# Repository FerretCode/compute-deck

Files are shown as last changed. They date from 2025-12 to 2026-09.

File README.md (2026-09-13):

# Compute Deck

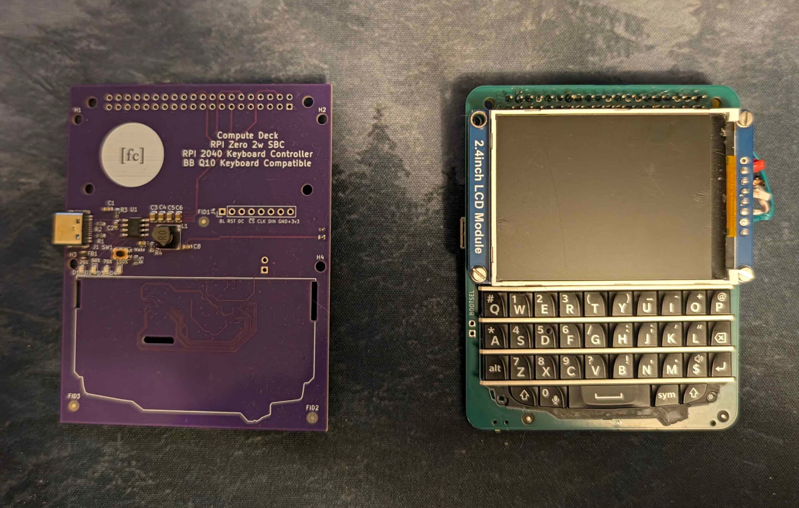
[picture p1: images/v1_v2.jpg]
Compute Deck v1 & v2


**Compute Deck** is an open-source portable Linux computer and cyberdeck platform. It features a BlackBerry Q10 physical keyboard, dedicated power management with LiPo charging, an RP2040 coprocessor serving as an I2C keyboard bridge, and a Linux compute module.

> [!WARNING]
> ### ⚠️ Hardware Revision Notice: RK3566 Migration In Progress
>
> Revisions 1 and 2 of this project were built and verified around a **Raspberry Pi Zero / Zero 2 W** form-factor header.
>
> The project is currently undergoing a major hardware architecture update to migrate from the Pi Zero header to an integrated Rockchip RK3566 SoC directly on the board.
---

## Project Overview & Key Features

- **Physical Keyboard Integration:** Uses a BlackBerry Q10 keyboard connected using a 24-pin Hirose BM14B connector.
- **Dedicated RP2040 Coprocessor:** Offloads the keyboard control from the processor, supporting debouncing, key remapping, and layer management.
- **I2C Slave Keyboard Bridge:** Communicates with the host system via I2C at address `0x1F`, sending keycodes to the main processor.
- **Power Management Subsystem:** Integrated IP5306 power bank SoC managing single-cell LiPo battery charging, 5V boost conversion, power routing, status LEDs, and soft-latching power control alongside an AMS1117-3.3 regulator.
- **Linux Host Virtual Keyboard Driver:** Python user-space daemon using Linux `/dev/uinput` and `evdev` to translate the RP2040 I2C keycodes into full USB keyboard input with support for modifiers.

---

## Repository Structure

```
compute-deck/
├── firmware/                   # RP2040 Coprocessor Firmware (Pico SDK C/C++)
│   ├── CMakeLists.txt          # CMake build configuration
│   ├── main.c                  # Keyboard matrix scanner, layer logic & I2C slave handler
├── hardware/                   # KiCad PCB & Schematic Design Files
│   ├── footprints/             # Custom KiCad component footprints
│   ├── symbols/                # Custom KiCad schematic symbols
├── host/                       # Host Linux Software & Services
│   ├── keyboard_driver.py      # Python I2C polling daemon & uinput event injector
│   ├── q10-keyboard.service    # Systemd service unit for boot startup
```

---

## RP2040 Firmware Setup

### Build Prerequisites

- [Raspberry Pi Pico SDK](https://github.com/raspberrypi/pico-sdk) configured in your environment (`PICO_SDK_PATH`).
- `cmake`
- GCC ARM Cross-compiler (`arm-none-eabi-gcc`)

### Building the Firmware

```bash
cd firmware
mkdir build
cd build
cmake ..
make -j$(nproc)
```

### Flashing

1. Short the `BOOTSEL` jumper on the board using tweezers or other conductive object while plugging in USB to enter the RP2040 into bootloader mode.
2. Drag and drop `q10_keyboard.uf2` onto the mounted `RPI-RP2` USB storage drive.

---

## Host Driver Setup (Linux / Raspberry Pi OS)

The host driver in `host/` runs on the Linux compute host (e.g. Raspberry Pi OS or Linux kernel with `/dev/uinput` enabled).

### 1. Enable I2C Interface
Enable the hardware I2C interface on the host SBC:

```bash
sudo raspi-config nonint do_i2c 0
```

### 2. Install Dependencies
```bash
sudo apt-get install python3-pip python3-smbus
pip3 install -r host/requirements.txt
```

### 3. Grant Permissions

Add your user to the `i2c` and `input` groups:

```bash
sudo usermod -aG i2c,input $USER
```

### 4. Running the Driver

Run the driver manually to verify key injection:

```bash
python3 host/keyboard_driver.py
```

### 5. Install as a Systemd Daemon

To launch the keyboard driver automatically at boot:

```bash
sudo mkdir -p /opt/q10-keyboard
sudo cp host/keyboard_driver.py /opt/q10-keyboard/
sudo cp host/q10-keyboard.service /etc/systemd/system/
sudo systemctl daemon-reload
sudo systemctl enable --now q10-keyboard.service
```

---

## Keyboard Layout & Modifier Behavior

The physical layout follows the BlackBerry Q10 matrix mapping:

- **Shift:** One-shot modifier. Pressing Shift capitalizes the next key typed, and then automatically clears.
- **Alt:** Accesses numbers and secondary symbols printed on keycaps (e.g., Q -> `#`, W -> `1`, E -> `2`).
- **Sym:** Accesses extended navigation and punctuation symbols (e.g., Q -> `Esc`, W -> `Up`, A -> `Left`, S -> `Down`, D -> `Right`, T -> `Tab`).
- **Mic Key:** Mapped as Super. Supports tap-or-chord timeout (`0.4s`).
- **Ctrl:** Left Control key with chord support.

---

## Fabrication & Manufacturing

Production files generated for JLCPCB are stored under `hardware/production/`

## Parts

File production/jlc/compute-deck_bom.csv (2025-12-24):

Designator | Footprint | Quantity | Value | LCSC Part #
A1 | RASPBERRYPI-ZERO_RPI-ZERO | 1 | RASPBERRYPI-ZERO
C1, C2 | 0603 | 2 | 10u | C19702
C10, C11, C13, C14, C16, C17, C18, C23 | 0402 | 8 | 100n | C71687
C12 | 0603 | 1 | 1u | C14445
C15 | 0402 | 1 | 100n
C20 | 0603 | 1 | 100n | C1590
C21, C22 | 0402 | 2 | 15p | C1548
C3, C4, C5, C6 | 0805 | 4 | 22u | C29277
C7, C8 | 0603 | 2 | 22u | C60077
C9 | 0402 | 1 | 1u | C14445
D1, D2, D3, D4 | 0603 | 4 | LED_Small | C6695603
FB1 | 0603 | 1 | 600R | C1017
J1 | USB_C_Receptacle_HRO_TYPE-C-31-M-12 | 1 | USB_C_Receptacle_USB2.0_16P | C165948
J2 | JST_PH_S2B-PH-K_1x02_P2.00mm_Horizontal | 1 | Conn_01x02 | C157932
L1 | L_Taiyo-Yuden_NR-60xx | 1 | 1uH | C2903082
Q1 | SOT-23 | 1 | BSS138 | C52895
R1, R2 | 0603 | 2 | 5.1k | C23186
R10, R5 | 0603 | 2 | 10k | C25804
R3 | 0603 | 1 | 2R | C22977
R4 | 0603 | 1 | 0.5R | C45312
R6, R7 | 0603 | 2 | 27.4 | C177713
R8, R9 | 0603 | 2 | 1k | C21190
SW1 | SW_Push_1P1T_NO_CK_KMR2 | 1 | SW_Push | C221675
U1 | SOP127P600X165-9N | 1 | IP5306
U2 | QFN-56-1EP_7x7mm_P0.4mm_EP3.2x3.2mm | 1 | RP2040 | C2040
U3 | SOIC-8_5.3x5.3mm_P1.27mm | 1 | W25Q128JVS
U4 | BM14B(0.8)-24DS-0.4V(53) | 1 | BBQ10KBD
Y1 | Crystal_SMD_3225-4Pin_3.2x2.5mm | 1 | 12MHz | C9002

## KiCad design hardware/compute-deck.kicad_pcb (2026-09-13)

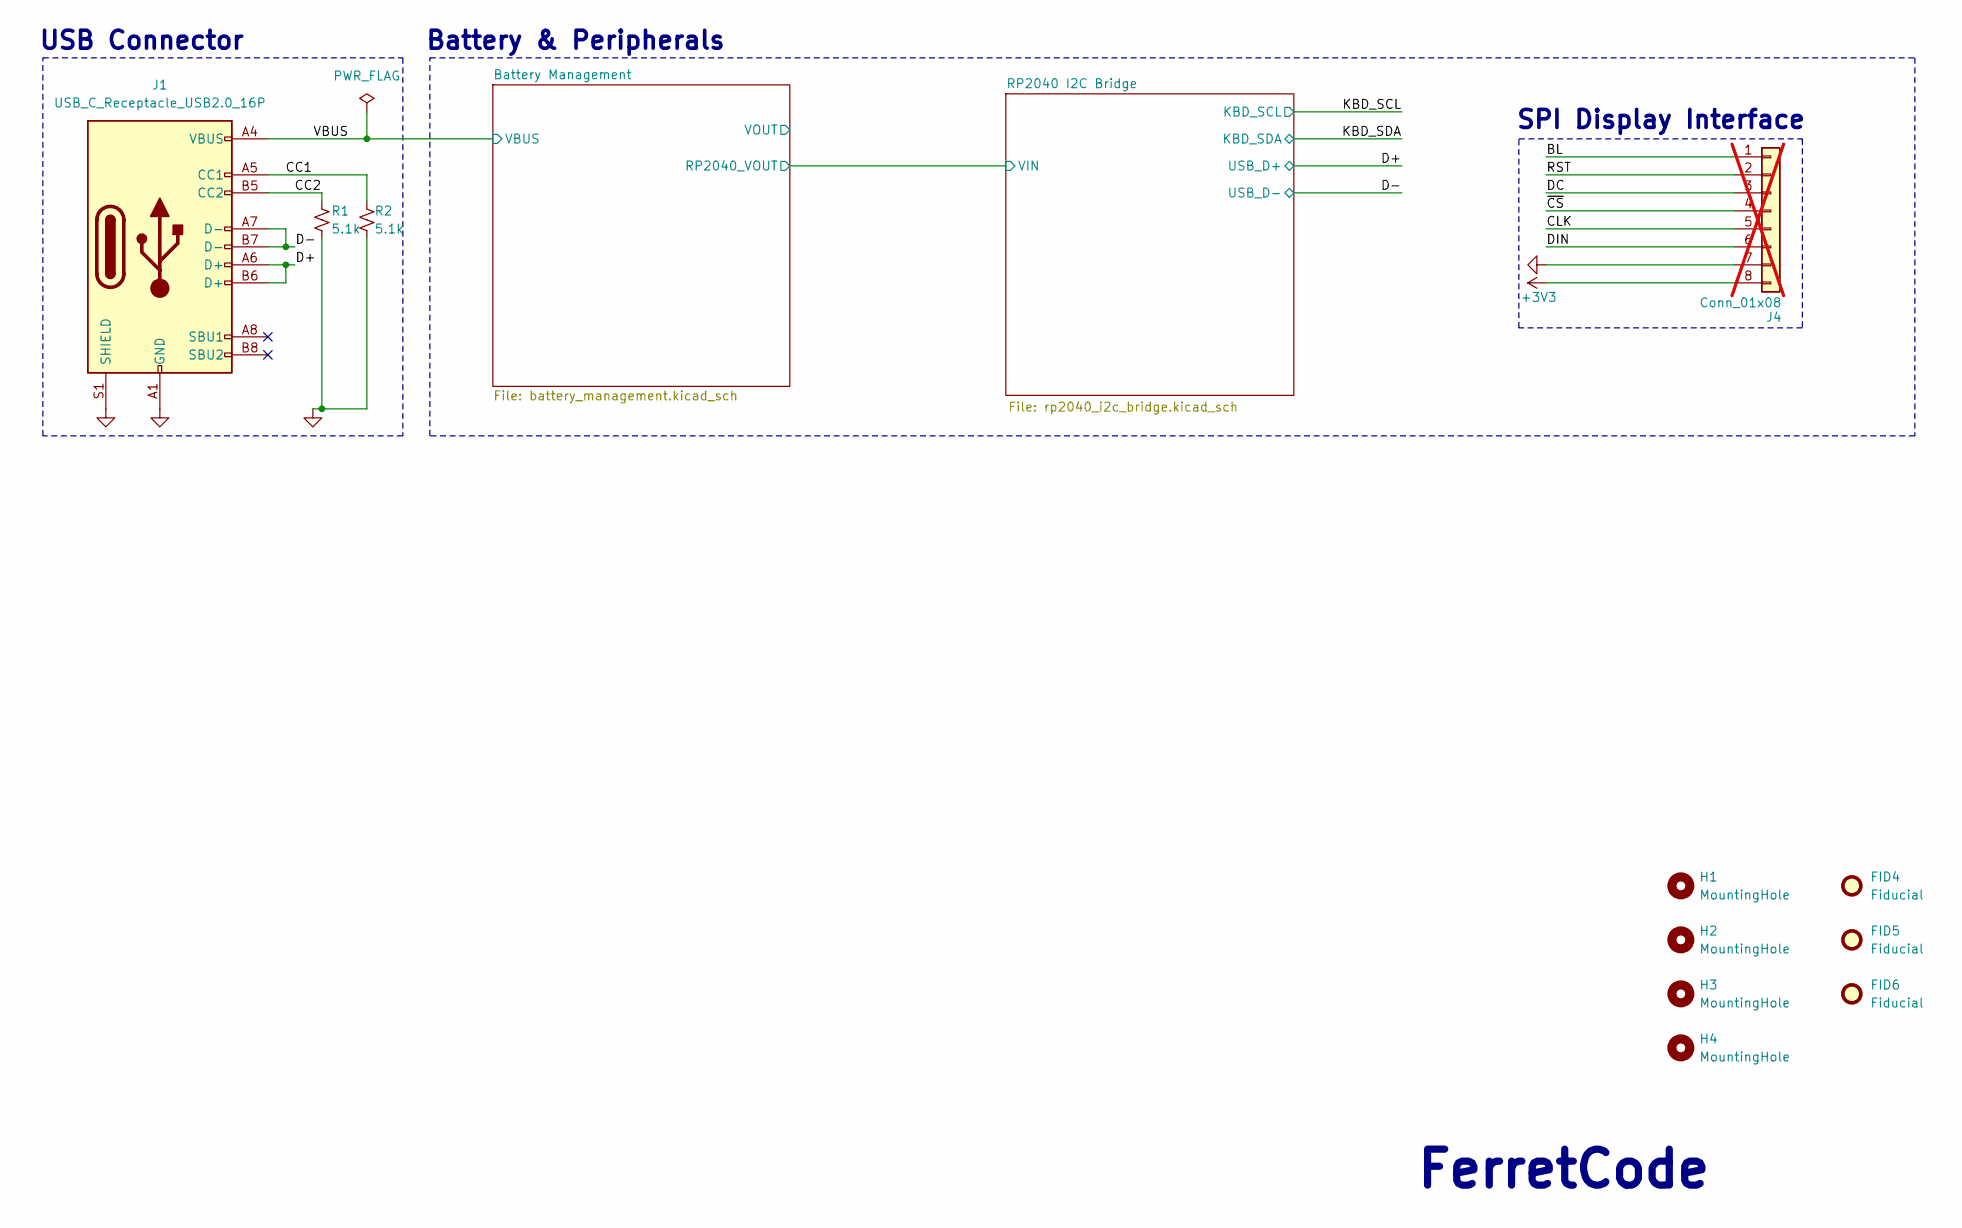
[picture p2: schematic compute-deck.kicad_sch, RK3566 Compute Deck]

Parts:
FID4, FID5, FID6: Fiducial; Fiducial_1mm_Mask3mm
H1, H2, H3, H4: MountingHole; MountingHole_2.7mm_M2.5
J1: USB_C_Receptacle_USB2.0_16P; USB_C_Receptacle_HRO_TYPE-C-31-M-12; LCSC PN C165948
J4: Conn_01x08; PinHeader_1x08_P2.54mm_Vertical; not fitted
R1, R2: 5.1k; R_0402_1005Metric; LCSC PN C23186

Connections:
+3V3: J4.8; also elsewhere on the board
/BL: J4.1; also elsewhere on the board
/CC1: J1.A5 (CC1), R2.1
/CC2: J1.B5 (CC2), R1.1
/CLK: J4.5; also elsewhere on the board
/D+: J1.A6 (D+), J1.B6 (D+); also elsewhere on the board
/D-: J1.A7 (D-), J1.B7 (D-); also elsewhere on the board
/DC: J4.3; also elsewhere on the board
/DIN: J4.6; also elsewhere on the board
/RST: J4.2; also elsewhere on the board
/VBUS: J1.A4 (VBUS), J1.A9 (VBUS), J1.B4 (VBUS), J1.B9 (VBUS); also elsewhere on the board
/~CS: J4.4; also elsewhere on the board
GND: J1.A1 (GND), J1.A12 (GND), J1.B1 (GND), J1.B12 (GND), J1.S1 (SHIELD), J4.7, R1.2, R2.2; also elsewhere on the board

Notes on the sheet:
Battery & Peripherals
FerretCode
SPI Display Interface
USB Connector

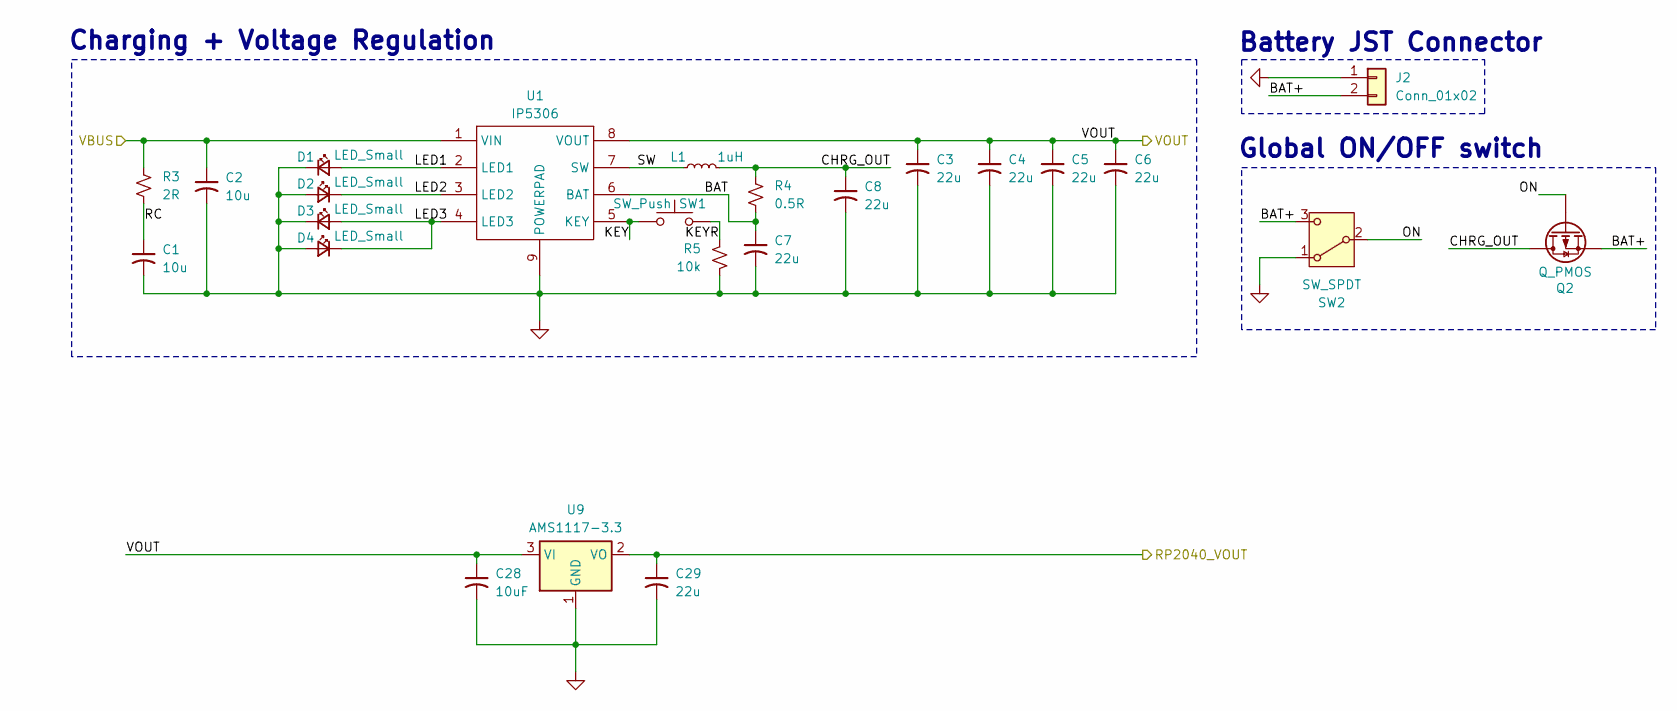
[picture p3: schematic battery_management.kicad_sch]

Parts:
C1, C2: 10u; C_0603_1608Metric; LCSC PN C19702
C3, C4, C5, C6: 22u; C_0805_2012Metric; LCSC PN C29277
C7: 22u; C_0402_1005Metric; LCSC PN C60077
C8: 22u; C_0603_1608Metric; LCSC PN C60077
C28: 10uF; C_0603_1608Metric; LCSC C19702
C29: 22u; C_0603_1608Metric; LCSC C59461
D1, D2, D3, D4: LED_Small; LED_0603_1608Metric; LCSC PN C6695603
J2: Conn_01x02; JST_PH_S2B-PH-K_1x02_P2.00mm_Horizontal; LCSC PN C157932
L1: 1uH; L_Taiyo-Yuden_NR-60xx; LCSC PN C2903082
Q2: Q_PMOS; SOT-23
R3: 2R; R_0603_1608Metric; LCSC PN C22977
R4: 0.5R; R_0402_1005Metric; LCSC PN C45312
R5: 10k; R_0402_1005Metric; LCSC PN C25804
SW1: SW_Push; SW_Push_1P1T_NO_CK_KMR2; LCSC PN C221675
SW2: SW_SPDT; SW_SPDT_PCM12
U1: IP5306; SOP127P600X165-9N
U9: AMS1117-3.3; SOT-223-3_TabPin2; LCSC C6186

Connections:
/BAT: C7.1, R4.2, U1.6 (BAT)
/BAT+: J2.2, Q2.S, SW2.3 (C)
/CHRG_OUT: C8.1, L1.2, Q2.D, R4.1
/KEY: SW1.1, U1.5 (KEY)
/KEYR: R5.1, SW1.2
/LED1: D1.2 (A), U1.2 (LED1)
/LED2: D2.1 (K), U1.3 (LED2)
/LED3: D3.2 (A), D4.1 (K), U1.4 (LED3)
/ON: Q2.G, SW2.2 (B)
/RC: C1.1, R3.2
/SW: L1.1, U1.7 (SW)
/VBUS: C2.1, R3.1, U1.1 (VIN); also elsewhere on the board
/VOUT: C3.1, C4.1, C5.1, C6.1, C28.1, U1.8 (VOUT), U9.3 (VI); also elsewhere on the board
GND: C1.2, C2.2, C3.2, C4.2, C5.2, C6.2, C7.2, C8.2, C28.2, C29.2, D1.1 (K), D2.2 (A), D3.1 (K), D4.2 (A), J2.1, R5.2, SW2.1 (A), U1.9 (POWERPAD), U9.1 (GND); also elsewhere on the board
unnamed: C29.1, U9.2 (VO)

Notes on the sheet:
Charging + Voltage Regulation
Global ON/OFF switch
Battery JST Connector

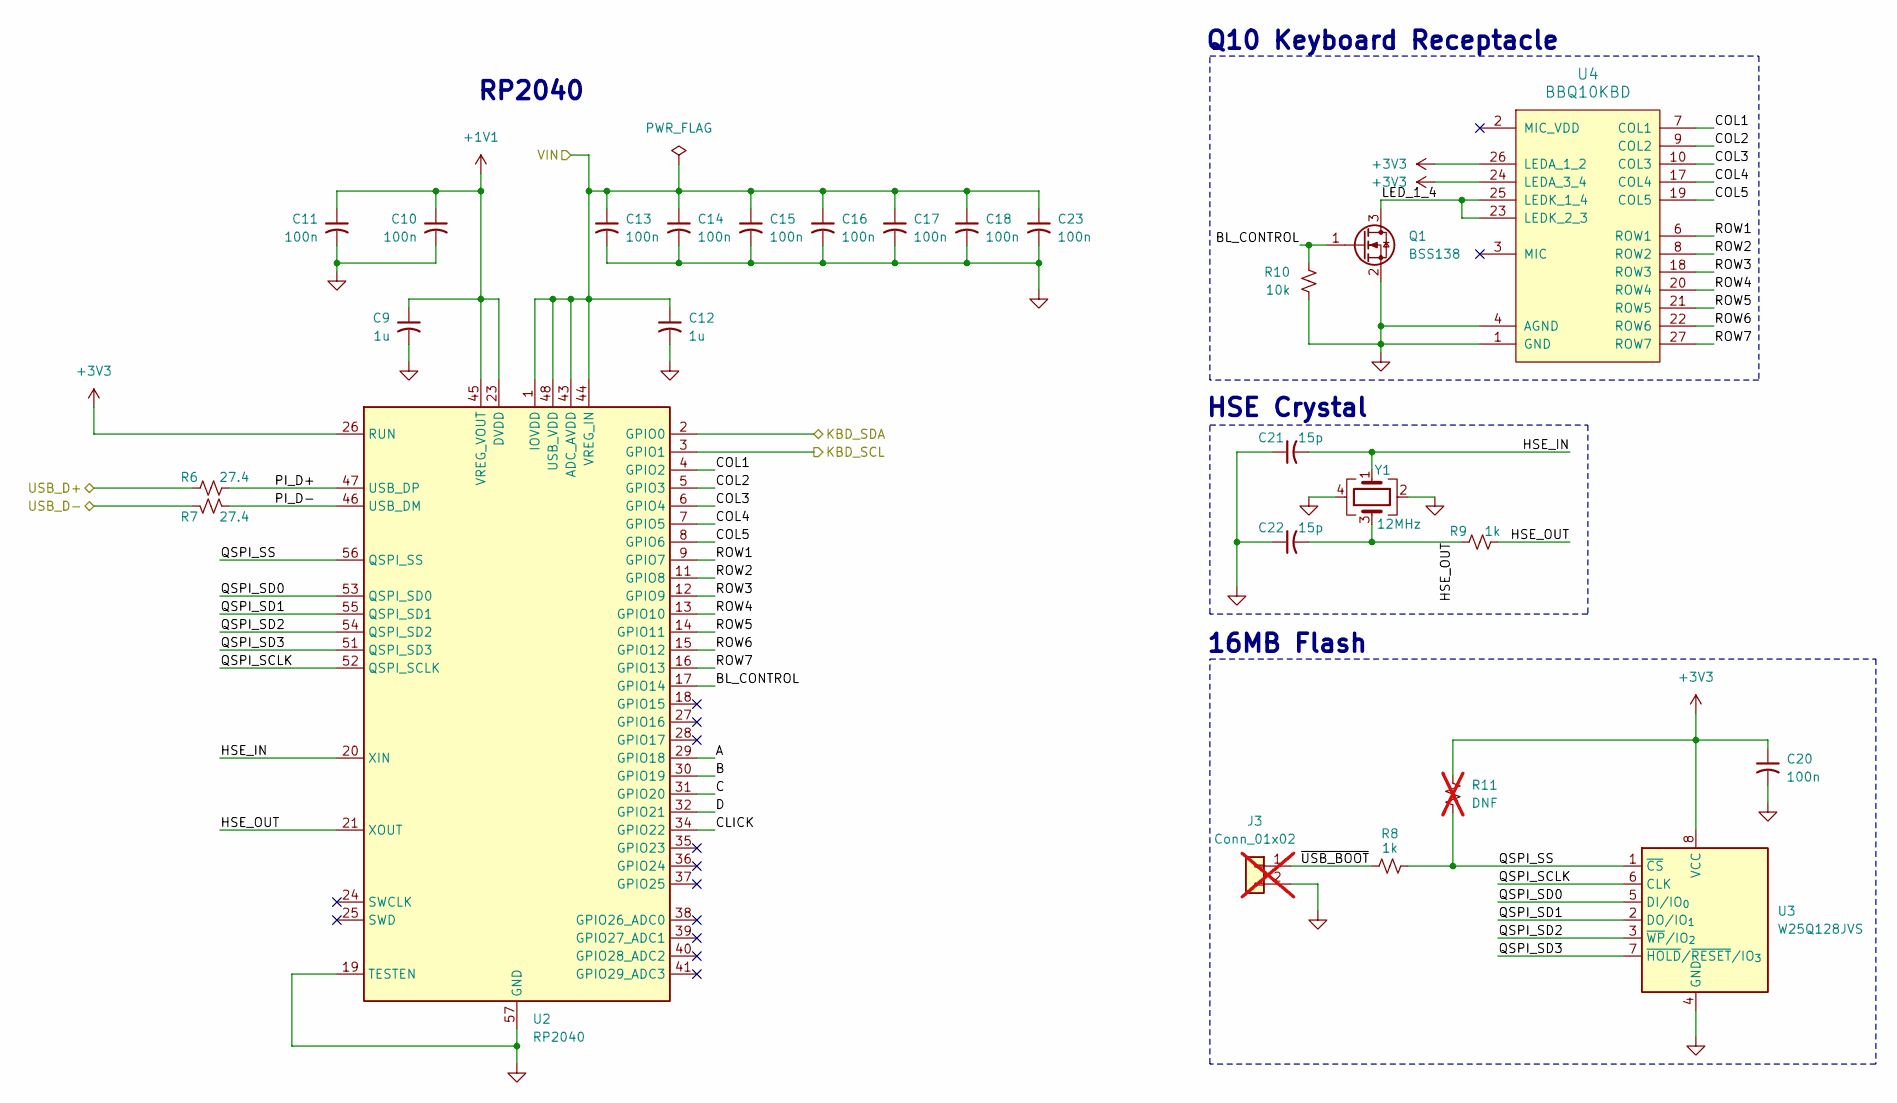
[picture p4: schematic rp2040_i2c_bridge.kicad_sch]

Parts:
C9: 1u; C_0402_1005Metric; LCSC PN C14445
C10, C11, C13, C14, C16, C17, C18: 100n; C_0402_1005Metric; LCSC PN C71687
C12: 1u; C_0603_1608Metric; LCSC PN C14445
C15: 100n; C_0402_1005Metric
C20: 100n; C_0603_1608Metric; LCSC PN C1590
C21, C22: 15p; C_0402_1005Metric; LCSC PN C1548
C23: 100n; C_0402_1005Metric_Pad0.74x0.62mm_HandSolder; LCSC PN C71687
J3: Conn_01x02; PinHeader_1x02_P2.54mm_Vertical; not fitted
Q1: BSS138; SOT-23; LCSC PN C52895
R6, R7: 27.4; R_0402_1005Metric; LCSC PN C177713
R8, R9: 1k; R_0402_1005Metric; LCSC PN C21190
R10: 10k; R_0603_1608Metric; LCSC PN C25804
R11: DNF; R_0402_1005Metric; not fitted
U2: RP2040; QFN-56-1EP_7x7mm_P0.4mm_EP3.2x3.2mm; LCSC PN C2040
U3: W25Q128JVS; SOIC-8_5.3x5.3mm_P1.27mm
U4: BBQ10KBD; BM14B(0.8)-24DS-0.4V(53)
Y1: 12MHz; Crystal_SMD_3225-4Pin_3.2x2.5mm; LCSC PN C9002

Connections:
+1V1: C9.1, C10.1, C11.1, U2.23 (DVDD), U2.45 (VREG_VOUT), U2.50 (DVDD)
+3V3: C12.1, C13.1, C14.1, C15.1, C16.1, C17.1, C18.1, C20.1, C23.1, R11.1, U2.1 (IOVDD), U2.10 (IOVDD), U2.22 (IOVDD), U2.26 (RUN), U2.33 (IOVDD), U2.42 (IOVDD), U2.43 (ADC_AVDD), U2.44 (VREG_IN), U2.48 (USB_VDD), U2.49 (IOVDD), U3.8 (VCC), U4.24 (LEDA_3_4), U4.26 (LEDA_1_2); also elsewhere on the board
/D+: R6.1; also elsewhere on the board
/D-: R7.1; also elsewhere on the board
/KBD_SCL: U2.3 (GPIO1); also elsewhere on the board
/KBD_SDA: U2.2 (GPIO0); also elsewhere on the board
/RP2040 I2C Bridge/A: U2.29 (GPIO18)
/RP2040 I2C Bridge/B: U2.30 (GPIO19)
/RP2040 I2C Bridge/BL_CONTROL: Q1.1 (G), R10.1, U2.17 (GPIO14)
/RP2040 I2C Bridge/C: U2.31 (GPIO20)
/RP2040 I2C Bridge/CLICK: U2.34 (GPIO22)
/RP2040 I2C Bridge/COL1: U2.4 (GPIO2), U4.7 (COL1)
/RP2040 I2C Bridge/COL2: U2.5 (GPIO3), U4.9 (COL2)
/RP2040 I2C Bridge/COL3: U2.6 (GPIO4), U4.10 (COL3)
/RP2040 I2C Bridge/COL4: U2.7 (GPIO5), U4.17 (COL4)
/RP2040 I2C Bridge/COL5: U2.8 (GPIO6), U4.19 (COL5)
/RP2040 I2C Bridge/D: U2.32 (GPIO21)
/RP2040 I2C Bridge/HSE_IN: C21.2, U2.20 (XIN), Y1.1
/RP2040 I2C Bridge/HSE_OUT: C22.2, R9.1, R9.2, U2.21 (XOUT), Y1.3
/RP2040 I2C Bridge/LED_1_4: Q1.3 (D), U4.23 (LEDK_2_3), U4.25 (LEDK_1_4)
/RP2040 I2C Bridge/PI_D+: R6.2, U2.47 (USB_DP)
/RP2040 I2C Bridge/PI_D-: R7.2, U2.46 (USB_DM)
/RP2040 I2C Bridge/QSPI_SCLK: U2.52 (QSPI_SCLK), U3.6 (CLK)
/RP2040 I2C Bridge/QSPI_SD0: U2.53 (QSPI_SD0), U3.5 (DI/IO_{0})
/RP2040 I2C Bridge/QSPI_SD1: U2.55 (QSPI_SD1), U3.2 (DO/IO_{1})
/RP2040 I2C Bridge/QSPI_SD2: U2.54 (QSPI_SD2), U3.3 (~WP/IO_{2})
/RP2040 I2C Bridge/QSPI_SD3: U2.51 (QSPI_SD3), U3.7 (~HOLD/~RESET/IO_{3})
/RP2040 I2C Bridge/QSPI_SS: R8.2, R11.2, U2.56 (QSPI_SS), U3.1 (~CS)
/RP2040 I2C Bridge/ROW1: U2.9 (GPIO7), U4.6 (ROW1)
/RP2040 I2C Bridge/ROW2: U2.11 (GPIO8), U4.8 (ROW2)
/RP2040 I2C Bridge/ROW3: U2.12 (GPIO9), U4.18 (ROW3)
/RP2040 I2C Bridge/ROW4: U2.13 (GPIO10), U4.20 (ROW4)
/RP2040 I2C Bridge/ROW5: U2.14 (GPIO11), U4.21 (ROW5)
/RP2040 I2C Bridge/ROW6: U2.15 (GPIO12), U4.22 (ROW6)
/RP2040 I2C Bridge/ROW7: U2.16 (GPIO13), U4.27 (ROW7)
/RP2040 I2C Bridge/~USB_BOOT: J3.1, R8.1
GND: C9.2, C10.2, C11.2, C12.2, C13.2, C14.2, C15.2, C16.2, C17.2, C18.2, C20.2, C21.1, C22.1, C23.2, J3.2, Q1.2 (S), R10.2, U2.19 (TESTEN), U2.57 (GND), U3.4 (GND), U4.1 (GND), U4.4 (AGND), U4.5 (GND), U4.11 (GND), U4.12 (GND), U4.13 (GND), U4.14 (GND), U4.15 (GND), U4.16 (GND), U4.28 (GND), Y1.2, Y1.4; also elsewhere on the board

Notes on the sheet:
Q10 Keyboard Receptacle
RP2040
16MB Flash
HSE Crystal

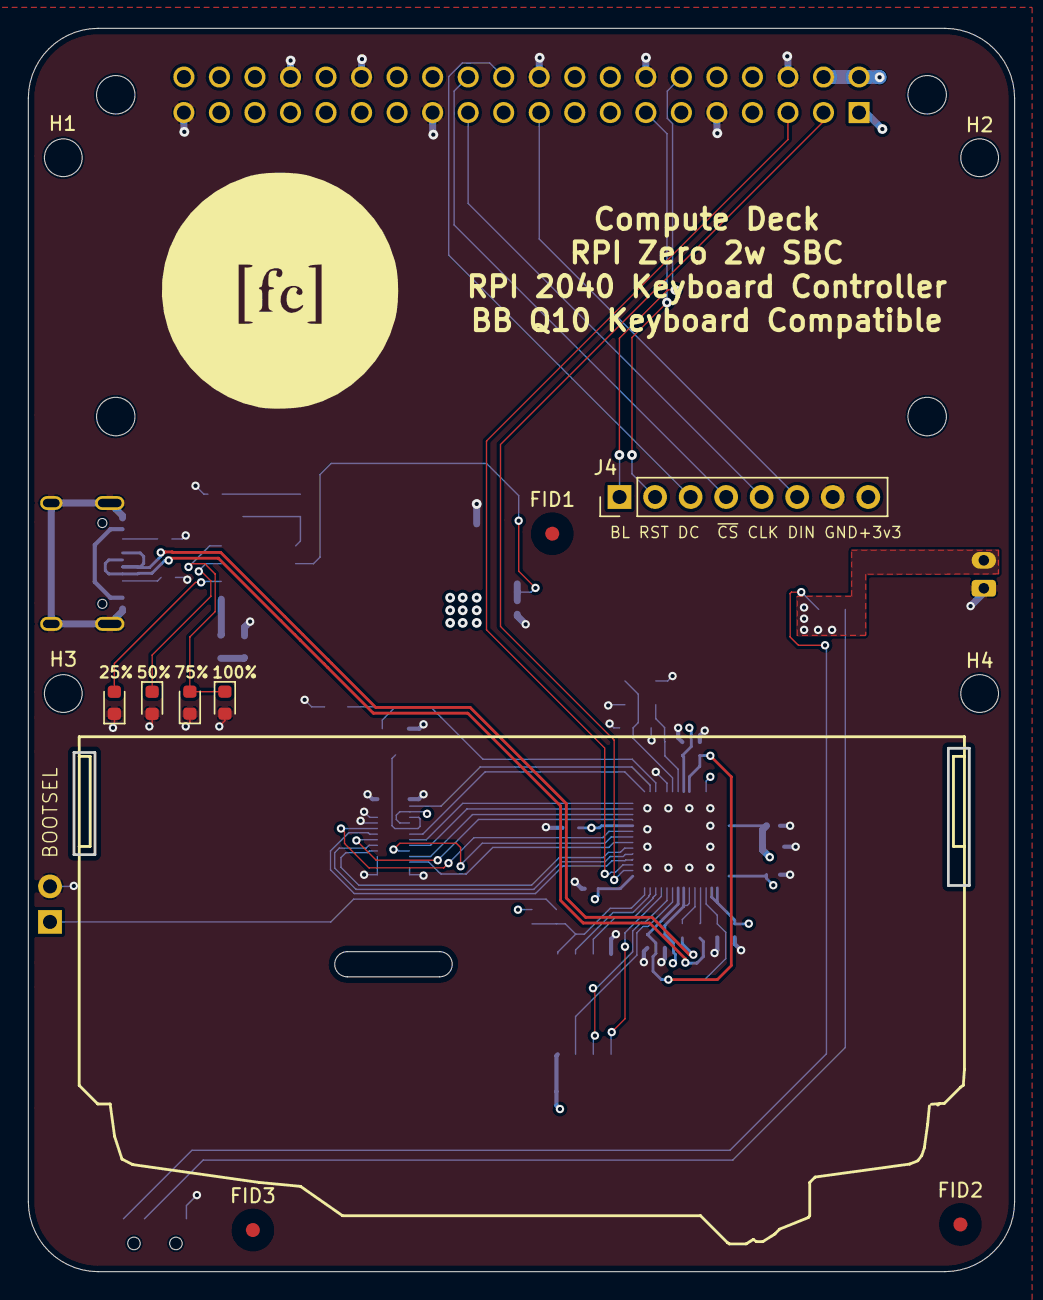
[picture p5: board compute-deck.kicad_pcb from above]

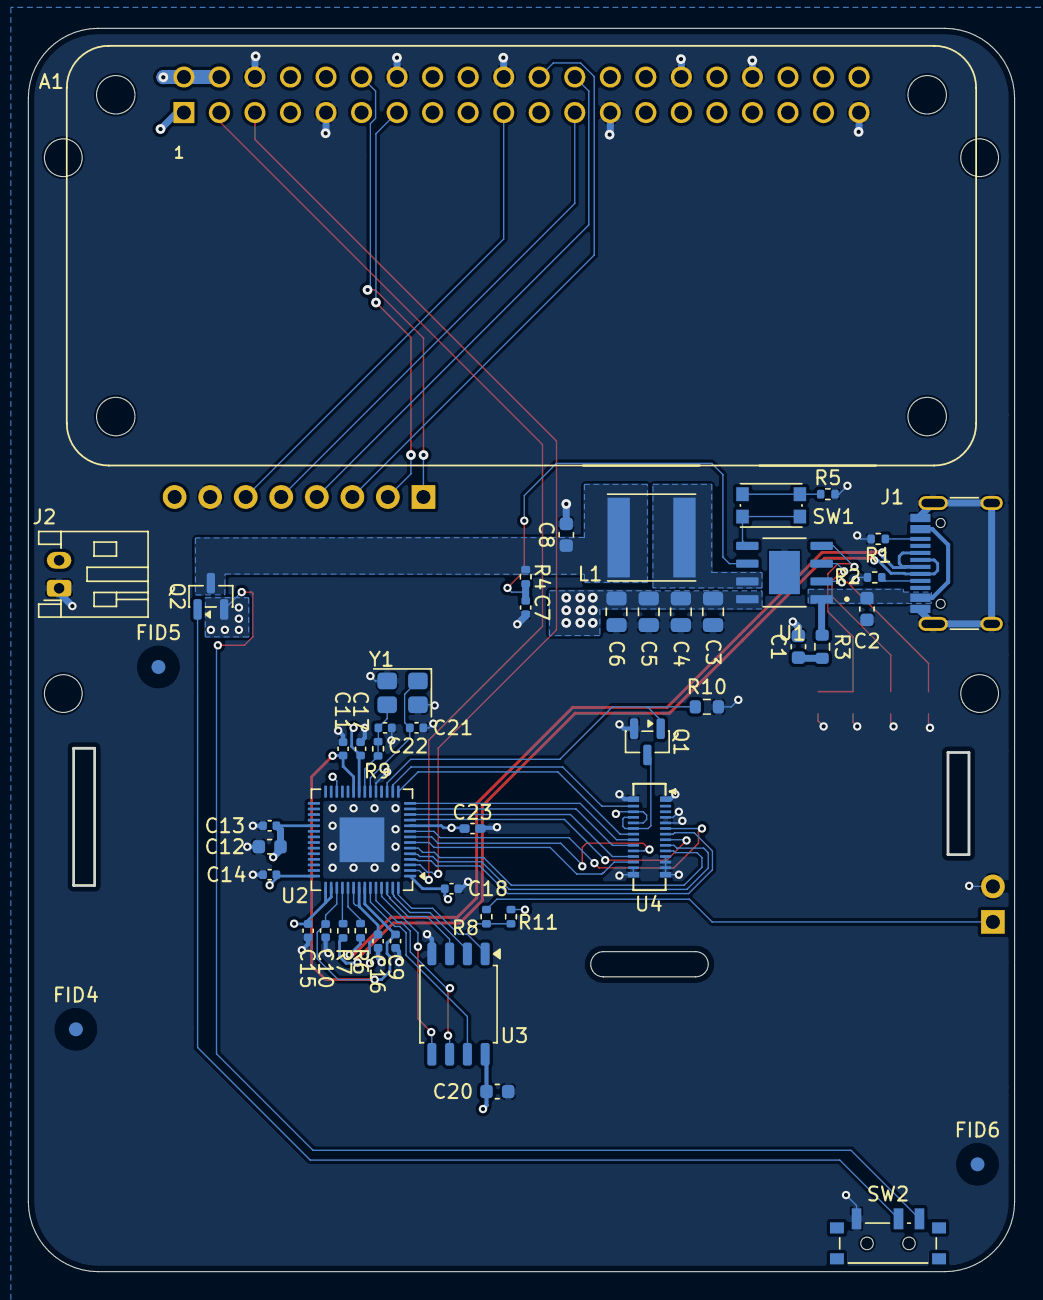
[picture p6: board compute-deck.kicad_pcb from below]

Board: 4 copper layers, 70.5 x 88.9 mm, 62 parts (50 on the bottom side), 53 nets.

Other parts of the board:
A1: RASPBERRYPI-ZERO; RASPBERRYPI-ZERO_RPI-ZERO
FID1, FID2, FID3: Fiducial; Fiducial_1mm_Mask3mm

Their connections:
+3V3: A1.1 (3V3[1]); also elsewhere on the board
/BL: A1.12 (GPIO18); also elsewhere on the board
/CLK: A1.23 (GPIO11/SCLK); also elsewhere on the board
/DC: A1.22 (GEN/6GPIO25); also elsewhere on the board
/DIN: A1.19 (GPIO10/MOSI); also elsewhere on the board
/KBD_SCL: A1.5 (GPIO3/SCL); also elsewhere on the board
/KBD_SDA: A1.3 (GPIO2/SDA); also elsewhere on the board
/RST: A1.13 (GPIO27/GEN2); also elsewhere on the board
/VOUT: A1.2 (5V[1]), A1.4 (5V[2]); also elsewhere on the board
/~CS: A1.24 (~CE0/GPIO8); also elsewhere on the board
GND: A1.6 (GND[8]), A1.9 (GND[1]), A1.14 (GND[4]), A1.20 (GND[5]), A1.25 (GND[2]), A1.30 (GND[6]), A1.34 (GND[7]), A1.39 (GND[3]); also elsewhere on the board

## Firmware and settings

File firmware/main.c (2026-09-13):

#include "hardware/i2c.h"
#include "pico/i2c_slave.h"
#include "pico/stdlib.h"
#include <stdio.h>

#define I2C_ADDR 0x1F
#define I2C_BAUDRATE (100 * 1000)
#define I2C_SDA_PIN 0
#define I2C_SCL_PIN 1

#define DEBOUNCE_MS 10

const uint COLS[5] = {2, 3, 4, 5, 6};
const uint ROWS[7] = {7, 8, 9, 10, 11, 12, 13};

// \x01 = sym, \x02 = shift-R, \x03 = alt, \x04 = mic/super, \x05 = shift-L,
// \x06 = mute, \x07 = ctrl, \x08 = host_alt, \x0a = caps_lock, \x7f = delete,
// \x11 = up, \x12 = left, \x13 = down, \x14 = right
const char keymap[7][5] = {
    {'Q', 'E', 'R', 'U', 'O'},       // ROW1
    {'W', 'S', 'G', 'H', 'L'},       // ROW2
    {'\x01', 'D', 'T', 'Y', 'I'},    // ROW3
    {'A', 'P', '\x02', '\r', '\b'},  // ROW4
    {'\x03', 'X', 'V', 'B', '\x06'}, // ROW5 (\x06 = mute, alt gives $)
    {' ', 'Z', 'C', 'N', 'M'},       // ROW6
    {'\x04', '\x05', 'F', 'J', 'K'}, // ROW7 (\x04 = mic, alt gives 0)
};

// modifiers keep working while alt is held
const char keymap_alt[7][5] = {
    {'#', '2', '3', '_', '+'},      // ROW1: Q E R U O
    {'1', '4', '/', ':', '"'},      // ROW2: W S G H L
    {'\x01', '5', '(', ')', '-'},   // ROW3: sym D T Y I
    {'*', '@', '\x02', '\r', '\b'}, // ROW4: A P shift-R CR bksp
    {'\x03', '8', '?', '!', '$'},   // ROW5: alt X V B mute
    {' ', '7', '9', '\'', '.'},     // ROW6: space Z C N M
    {'0', '\x05', '6', ';', '`'},   // ROW7: mic shift-L F J K
};

// sym layer: shortcuts for missing modifier keys, navigation,
// and special symbols. '\0' means fall through to the lower keymap
const char keymap_sym[7][5] = {
    {'\x1b', '[', ']', 0, '='},    // ROW1: Q=Esc, E=[, R=], O==
    {'\x11', '\x13', '}', '^', 0}, // ROW2: W=Up, S=Down, G=}, H=^
    {0, '\x14', '\t', 0, 0},       // ROW3: D=Right, T=Tab
    {'\x12', '%', '\x0a', '\r',
     '\x7f'},                       // ROW4: A=Left, P=%, shift-R=Caps, bksp=Del
    {'\x08', '>', '\\', 0, '\x06'}, // ROW5: alt=HostAlt, X=>, V=\, mute=Mute
    {' ', '<', '\x07', '~', '|'},   // ROW6: Z=<, C=Ctrl, N=~, M=|
    {'\x04', '\x0a', '{', 0, 0},    // ROW7: mic=Super, shift-L=Caps, F={
};

static uint8_t last_keycode = 0;
static bool alt_held = false;
static bool sym_held = false;

static bool key_raw[7][5] = {0};
static bool key_debounced[7][5] = {0};
static uint32_t last_change_ms[7][5] = {0};

static void i2c_slave_handler(i2c_inst_t *i2c, i2c_slave_event_t event) {
    switch (event) {
    case I2C_SLAVE_REQUEST:
        i2c_get_hw(i2c)->data_cmd = last_keycode;
        last_keycode = 0;

        break;
    case I2C_SLAVE_RECEIVE:
        (void)i2c_get_hw(i2c)->data_cmd;

        break;
    case I2C_SLAVE_FINISH:
        break;
    }
}

static void handle_key_transition(int r, int c, bool pressed) {
    char base = keymap[r][c];

    if (base == '\x03') { // alt
        alt_held = pressed;
    } else if (base == '\x01') { // sym
        sym_held = pressed;
    }

    if (!pressed) {
        return;
    }

    char resolved;
    if (sym_held && keymap_sym[r][c] != '\0') {
        resolved = keymap_sym[r][c];
    } else if (alt_held) {
        resolved = keymap_alt[r][c];
    } else {
        resolved = base;
    }

    last_keycode = (uint8_t)resolved;

    printf("Key pressed: '%c' (Row%d, Col%d, alt=%d, sym=%d)\n", resolved, r, c,
           alt_held, sym_held);
}

int main(void) {
    stdio_init_all();
    sleep_ms(2000);
    printf("Starting Q10 Keyboard Firmware...\n");

    for (int i = 0; i < 7; i++) {
        gpio_init(ROWS[i]);
        gpio_set_dir(ROWS[i], GPIO_IN);
        gpio_pull_up(ROWS[i]);
    }

    for (int i = 0; i < 5; i++) {
        gpio_init(COLS[i]);
        gpio_set_dir(COLS[i], GPIO_IN);
        gpio_disable_pulls(COLS[i]);
    }

    i2c_init(i2c0, I2C_BAUDRATE);
    gpio_set_function(I2C_SDA_PIN, GPIO_FUNC_I2C);
    gpio_set_function(I2C_SCL_PIN, GPIO_FUNC_I2C);
    gpio_pull_up(I2C_SDA_PIN);
    gpio_pull_up(I2C_SCL_PIN);
    i2c_slave_init(i2c0, I2C_ADDR, i2c_slave_handler);

    while (true) {
        for (int c = 0; c < 5; c++) {
            gpio_set_dir(COLS[c], GPIO_OUT);
            gpio_put(COLS[c], 0);
            sleep_us(10); // allow signal to settle

            uint32_t now = to_ms_since_boot(get_absolute_time());

            for (int r = 0; r < 7; r++) {
                bool pressed = !gpio_get(ROWS[r]); // active low

                if (pressed != key_raw[r][c]) {
                    key_raw[r][c] = pressed;
                    last_change_ms[r][c] = now;
                }

                if ((now - last_change_ms[r][c]) >= DEBOUNCE_MS &&
                    key_raw[r][c] != key_debounced[r][c]) {
                    key_debounced[r][c] = key_raw[r][c];

                    handle_key_transition(r, c, key_debounced[r][c]);
                }
            }

            gpio_set_dir(COLS[c], GPIO_IN);
            gpio_disable_pulls(COLS[c]);
        }

        sleep_ms(1);
    }
}

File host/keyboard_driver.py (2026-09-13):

#!/usr/bin/env python3
"""
Runs on the Raspberry Pi Zero (2)W. This driver polls the RP2040 keyboard driver over I2C
and, replays each keycode as a virtual USB keyboard via /dev/uinput.

Setup on the Pi:
    sudo raspi-config nonint do_i2c 0     # enable the I2C interface
    pip3 install smbus2 evdev
    sudo usermod -aG i2c,input "$USER"    # or run this script as root
    sudo python3 keyboard_driver.py

Shift is a one-shot modifier, meaning pressing shift
just capitalizes/shifts the next character typed, then clears itself.

Modifier keys act are chorded/one-shot modifiers, meaning tapping one
starts a short window (SUPER_CHORD_TIMEOUT_S). If another key arrives inside
that window, it's replayed with the modifier held. If nothing
follows before the window closes, a bare tap of the modifier key is emitted.
"""

import time

import smbus2
from evdev import UInput, ecodes as e

I2C_BUS = 1
I2C_ADDR = 0x1F
POLL_INTERVAL_S = 0.005
KEY_HOLD_S = 0.008
SUPER_CHORD_TIMEOUT_S = 0.4

# control bytes from the firmware
SYM = "\x01"
SHIFT_R = "\x02"
ALT = "\x03"
MIC = "\x04"
SHIFT_L = "\x05"
MUTE = "\x06"
CTRL = "\x07"
HOST_ALT = "\x08"
CAPS_LOCK = "\x0a"
DELETE = "\x7f"

KEY_UP_BYTE = "\x11"
KEY_LEFT_BYTE = "\x12"
KEY_DOWN_BYTE = "\x13"
KEY_RIGHT_BYTE = "\x14"

MUTE_KEYCODE = e.KEY_MUTE
SUPER_KEYCODE = e.KEY_LEFTMETA
CTRL_KEYCODE = e.KEY_LEFTCTRL
ALT_KEYCODE = e.KEY_LEFTALT
SHIFT_KEYCODE = e.KEY_LEFTSHIFT
CAPS_KEYCODE = e.KEY_CAPSLOCK

# char -> (evdev keycode, needs_shift)
SYMBOL_MAP = {
    "1": (e.KEY_1, False),
    "2": (e.KEY_2, False),
    "3": (e.KEY_3, False),
    "4": (e.KEY_4, False),
    "5": (e.KEY_5, False),
    "6": (e.KEY_6, False),
    "7": (e.KEY_7, False),
    "8": (e.KEY_8, False),
    "9": (e.KEY_9, False),
    "0": (e.KEY_0, False),
    "#": (e.KEY_3, True),
    "_": (e.KEY_MINUS, True),
    "-": (e.KEY_MINUS, False),
    "+": (e.KEY_EQUAL, True),
    "/": (e.KEY_SLASH, False),
    ":": (e.KEY_SEMICOLON, True),
    ";": (e.KEY_SEMICOLON, False),
    "'": (e.KEY_APOSTROPHE, False),
    '"': (e.KEY_APOSTROPHE, True),
    "(": (e.KEY_9, True),
    ")": (e.KEY_0, True),
    "*": (e.KEY_8, True),
    "@": (e.KEY_2, True),
    "?": (e.KEY_SLASH, True),
    "!": (e.KEY_1, True),
    "$": (e.KEY_4, True),
    "`": (e.KEY_GRAVE, False),
    "|": (e.KEY_BACKSLASH, True),
    ".": (e.KEY_DOT, False),
    " ": (e.KEY_SPACE, False),
    "\r": (e.KEY_ENTER, False),
    "\b": (e.KEY_BACKSPACE, False),
    "\t": (e.KEY_TAB, False),
    "\x1b": (e.KEY_ESC, False),
    "\x7f": (e.KEY_DELETE, False),
    "\x11": (e.KEY_UP, False),
    "\x12": (e.KEY_LEFT, False),
    "\x13": (e.KEY_DOWN, False),
    "\x14": (e.KEY_RIGHT, False),
    "[": (e.KEY_LEFTBRACE, False),
    "]": (e.KEY_RIGHTBRACE, False),
    "{": (e.KEY_LEFTBRACE, True),
    "}": (e.KEY_RIGHTBRACE, True),
    "<": (e.KEY_COMMA, True),
    ">": (e.KEY_DOT, True),
    "=": (e.KEY_EQUAL, False),
    "^": (e.KEY_6, True),
    "%": (e.KEY_5, True),
    "\\": (e.KEY_BACKSLASH, False),
    "~": (e.KEY_GRAVE, True),
}

LETTER_KEYCODES = {c: getattr(e, f"KEY_{c}") for c in "ABCDEFGHIJKLMNOPQRSTUVWXYZ"}

MODIFIER_KEYCODES = {
    SHIFT_KEYCODE,
    CTRL_KEYCODE,
    ALT_KEYCODE,
    SUPER_KEYCODE,
    CAPS_KEYCODE,
}

CAPABILITIES = {
    e.EV_KEY: sorted(
        set(LETTER_KEYCODES.values())
        | {code for code, _ in SYMBOL_MAP.values()}
        | MODIFIER_KEYCODES
        | {MUTE_KEYCODE}
    ),
}


def resolve(ch, pending_shift):
    """Map a received character to (keycode, needs_shift), or (None, ...)."""
    if ch in LETTER_KEYCODES:
        return LETTER_KEYCODES[ch], pending_shift

    if ch in SYMBOL_MAP:
        code, needs_shift = SYMBOL_MAP[ch]

        return code, pending_shift or needs_shift

    return None, pending_shift


def tap(ui, code, modifiers=()):
    for mod in modifiers:
        ui.write(e.EV_KEY, mod, 1)
        ui.syn()

    ui.write(e.EV_KEY, code, 1)
    ui.syn()

    time.sleep(KEY_HOLD_S)

    ui.write(e.EV_KEY, code, 0)
    ui.syn()

    for mod in reversed(modifiers):
        ui.write(e.EV_KEY, mod, 0)
        ui.syn()


def main():
    bus = smbus2.SMBus(I2C_BUS)
    ui = UInput(CAPABILITIES, name="q10-keyboard")

    pending_shift = False
    pending_super_since = None
    pending_ctrl_since = None
    pending_alt_since = None

    print(f"Listening on I2C bus {I2C_BUS}, address 0x{I2C_ADDR:02X}...")

    try:
        while True:
            try:
                byte = bus.read_byte(I2C_ADDR)
            except OSError:
                byte = 0

            if byte != 0:
                ch = chr(byte)

                if ch in (SHIFT_L, SHIFT_R):
                    pending_shift = True
                elif ch in (ALT, SYM):
                    pass
                elif ch == MIC:
                    pending_super_since = time.monotonic()
                elif ch == CTRL:
                    pending_ctrl_since = time.monotonic()
                elif ch == HOST_ALT:
                    pending_alt_since = time.monotonic()
                elif ch == CAPS_LOCK:
                    tap(ui, CAPS_KEYCODE)
                elif ch == MUTE:
                    modifiers = []

                    if pending_shift:
                        modifiers.append(SHIFT_KEYCODE)
                        pending_shift = False

                    if pending_ctrl_since is not None:
                        modifiers.append(CTRL_KEYCODE)
                        pending_ctrl_since = None

                    if pending_alt_since is not None:
                        modifiers.append(ALT_KEYCODE)
                        pending_alt_since = None

                    if pending_super_since is not None:
                        modifiers.append(SUPER_KEYCODE)
                        pending_super_since = None

                    tap(ui, MUTE_KEYCODE, modifiers)
                else:
                    code, shift = resolve(ch, pending_shift)
                    pending_shift = False

                    if code is not None:
                        modifiers = []

                        if shift:
                            modifiers.append(SHIFT_KEYCODE)

                        if pending_ctrl_since is not None:
                            modifiers.append(CTRL_KEYCODE)
                            pending_ctrl_since = None

                        if pending_alt_since is not None:
                            modifiers.append(ALT_KEYCODE)
                            pending_alt_since = None

                        if pending_super_since is not None:
                            modifiers.append(SUPER_KEYCODE)
                            pending_super_since = None

                        tap(ui, code, modifiers)

            now = time.monotonic()
            if (
                pending_ctrl_since is not None
                and now - pending_ctrl_since > SUPER_CHORD_TIMEOUT_S
            ):
                modifiers = []
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

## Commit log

2025-12-24 add compute deck
    [compute-deck.kicad_pcb, compute-deck.kicad_pcb_bom.csv, compute-deck.kicad_pcb_positions.csv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]
2026-08-01 add revision 2
    [compute-deck.kicad_pcb, compute-deck.kicad_pcb_bom.csv, compute-deck.kicad_pcb_positions.csv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]
2026-09-13 start revision to on-board SoC
    [battery_management.kicad_sch, compute-deck.kicad_pcb, compute-deck.kicad_sch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]
